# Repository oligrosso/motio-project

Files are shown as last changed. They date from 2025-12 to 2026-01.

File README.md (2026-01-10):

# 🧠 MOTIO — Biomedical Instrumentation Project

**MOTIO** is an end-to-end **biomedical instrumentation system** designed for the **analysis and treatment support of Parkinson’s Disease**, providing a **non-invasive, portable, and objective** approach to motor symptom monitoring.

The project integrates **wearable hardware**, **embedded firmware**, and an **intelligent analysis platform**, enabling both clinical and ambulatory use.

> 🩺 *Making motion science accessible.*

---

## 🎯 Project Objective

The main goal of MOTIO is to develop and validate a system capable of:

- 🧤 Delivering **vibrotactile therapeutic stimulation**
- 📟 Objectively measuring motor symptoms, especially tremor
- 📊 Processing and visualizing motion data through a clinical interface
- 📈 Complementing (not replacing) traditional clinical assessments (e.g. MDS-UPDRS)

---

## 🧩 System Architecture Overview

### 📁 Repository Structure

- 🧤 **MotioGlove/** — Wearable vibrotactile therapeutic device  
- 📟 **MotioSensor/** — Portable inertial measurement device (IMU)  
- 📊 **MotioMetrics/** — Motion analysis and visualization platform  

Each module can operate independently, but together they form a **complete ecosystem** for treatment, measurement, and analysis.

---

## 🧤 MotioGlove — Vibrotactile Therapeutic Glove

Wearable glove designed to apply **Vibrotactile Coordinated Reset (vCR)** stimulation to the fingertips.

### 🔬 Scientific Background
Based on research by **Tass et al. (Stanford University)**, vCR aims to **desynchronize pathological neural networks** using controlled mechanical stimulation.

### ⚙️ Key Features
- Vibrotactile stimulation at **250 Hz**
- Alternating stimulation of **finger pairs**
- Randomized stimulation sequences (**Fisher–Yates algorithm**)
- Temporal pauses with **jitter**
- Autonomous **2-hour therapy sessions**
- Button-based control and LED feedback

### ✅ Advantages
- Non-invasive
- Portable
- Ambulatory use
- High patient comfort
- No reported side effects

---

## 📟 MotioSensor — Inertial Measurement Device

Portable sensing unit designed to objectively capture motion data with **clinical-grade precision**.

### 🧠 Measured Signals
- 3-axis acceleration
- 3-axis angular velocity
- Orientation estimation (Yaw, Pitch, Roll)

### 🔄 Operating Modes
- 🏥 **Clinical mode**: real-time WiFi transmission
- 🏠 **Ambulatory mode**: local storage on microSD card

### 📁 Output
- `.csv` files containing:
  - Raw sensor signals
  - Timestamped activity annotations

---

## 📊 MotioMetrics — Motion Analysis Platform

Software platform responsible for **data processing, analysis, and visualization**.

### 🧠 Backend (Python)
- CSV file ingestion
- Automatic signal processing
- Tremor episode detection
- Computation of:
  - Dominant frequency
  - RMS amplitude
  - Episode duration
- Spectral analysis (FFT + **Burg method**)

### 🖥️ Web Interface
- Clinical-oriented UI
- Manual CSV upload
- Interactive visualizations (Plotly.js)
- Patient data registration
- PDF report export
- Local measurement history

### 🔴 Real-Time Analysis
- **WebSocket-based** communication
- Live signal visualization
- Activity logging with timestamps
- Automatic download of recorded data at session end

---

## 🔁 System Workflow

### 🧪 Real-Time Analysis
```mermaid
flowchart LR
  A[MotioSensor] -->|WiFi / WebSockets| B[MotioMetrics backend]
  B --> C[Live processing]
  C --> D[Web interface]
  D --> E[Live visualization]
```

### 📂 Offline CSV Analysis

```mermaid
flowchart LR
  A[MotioSensor<br/>CSV files] --> B[MotioMetrics]
  B --> C[Signal processing]
  C --> D[Metrics extraction]
  D --> E[Reports and visualizations]
```
## 🧪 Validation & Results

The system was evaluated on:
- Parkinson’s patients with tremor
- Parkinson’s patients without tremor (dyskinesia)
- Control subjects

Results demonstrated:
- Strong correlation with clinical evaluation
- Robust tremor episode detection
- High usability and acceptance by patients and clinicians

---

## 🛠️ Technologies Used

- **Python** (signal processing & backend)
- **Flask + Socket.IO**
- **JavaScript / HTML / CSS**
- **Plotly.js**
- **ESP8266 (Wemos D1 Mini)**
- **MPU6050 IMU**
- **Render + GitHub**

---

## 👩‍🔬 Team

Developed as part of  
**Biomedical Instrumentation II — ITBA**

**Group 1**
- Alexa Sessarego Aurich
- Jazmín Azul Fermani  
- Olivia Grosso  
---

## ⚠️ Disclaimer

This project was developed for **academic and research purposes only**.  
It is **not a certified medical device** for commercial clinical use.

## 🗂️ Module Interaction Diagram
```mermaid
flowchart LR

  subgraph Wearables
    G[MotioGlove<br/>Vibrotactile therapy]
    P[Patient]
    S[MotioSensor<br/>IMU data acquisition]
    G -->|Therapy| P -->|Motion| S
  end

  subgraph Software
    B[MotioMetrics backend]
    W[Web interface]
    D[Desktop application]
    B --> W
    B --> D
  end

  S -->|Motion data| B

```

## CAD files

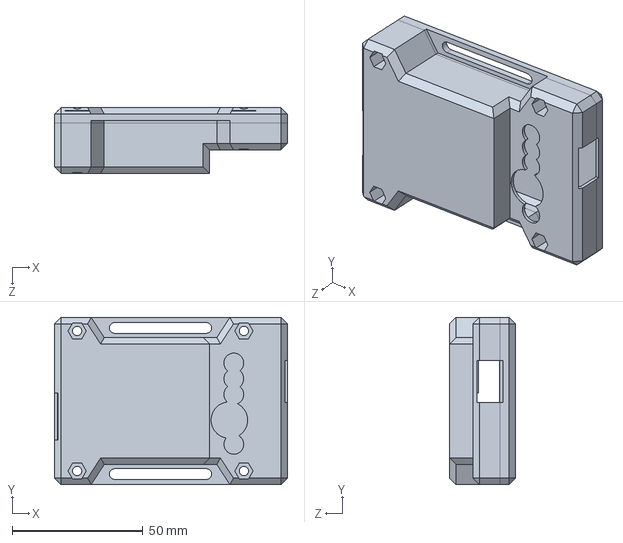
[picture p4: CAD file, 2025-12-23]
MotioGlove/3DPrint/MotioGlove_ambaspartes.SLDPRT
89.0 x 63.9 x 25.2 mm

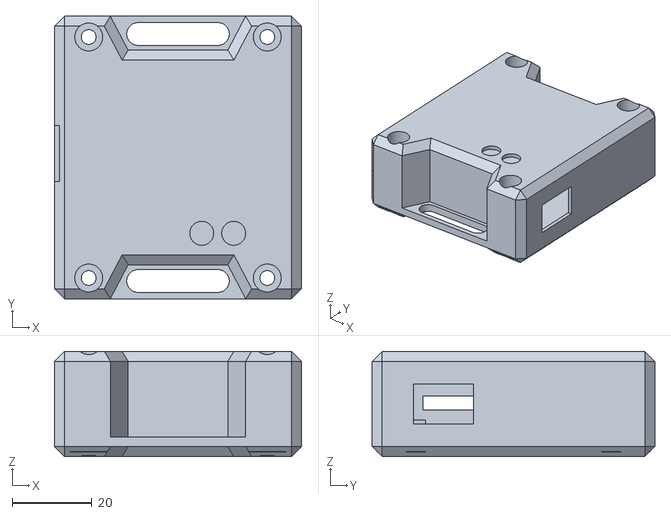
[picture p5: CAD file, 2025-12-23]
MotioSensor/3DPrint/MotioSensor_Carcasa.STL
61.9 x 70.8 x 26.4

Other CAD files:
MotioGlove/3DPrint/MotioGlove_carcasa_ambaspartes.STL
MotioSensor/3DPrint/MotioSensor_ambaspartes.SLDPRT

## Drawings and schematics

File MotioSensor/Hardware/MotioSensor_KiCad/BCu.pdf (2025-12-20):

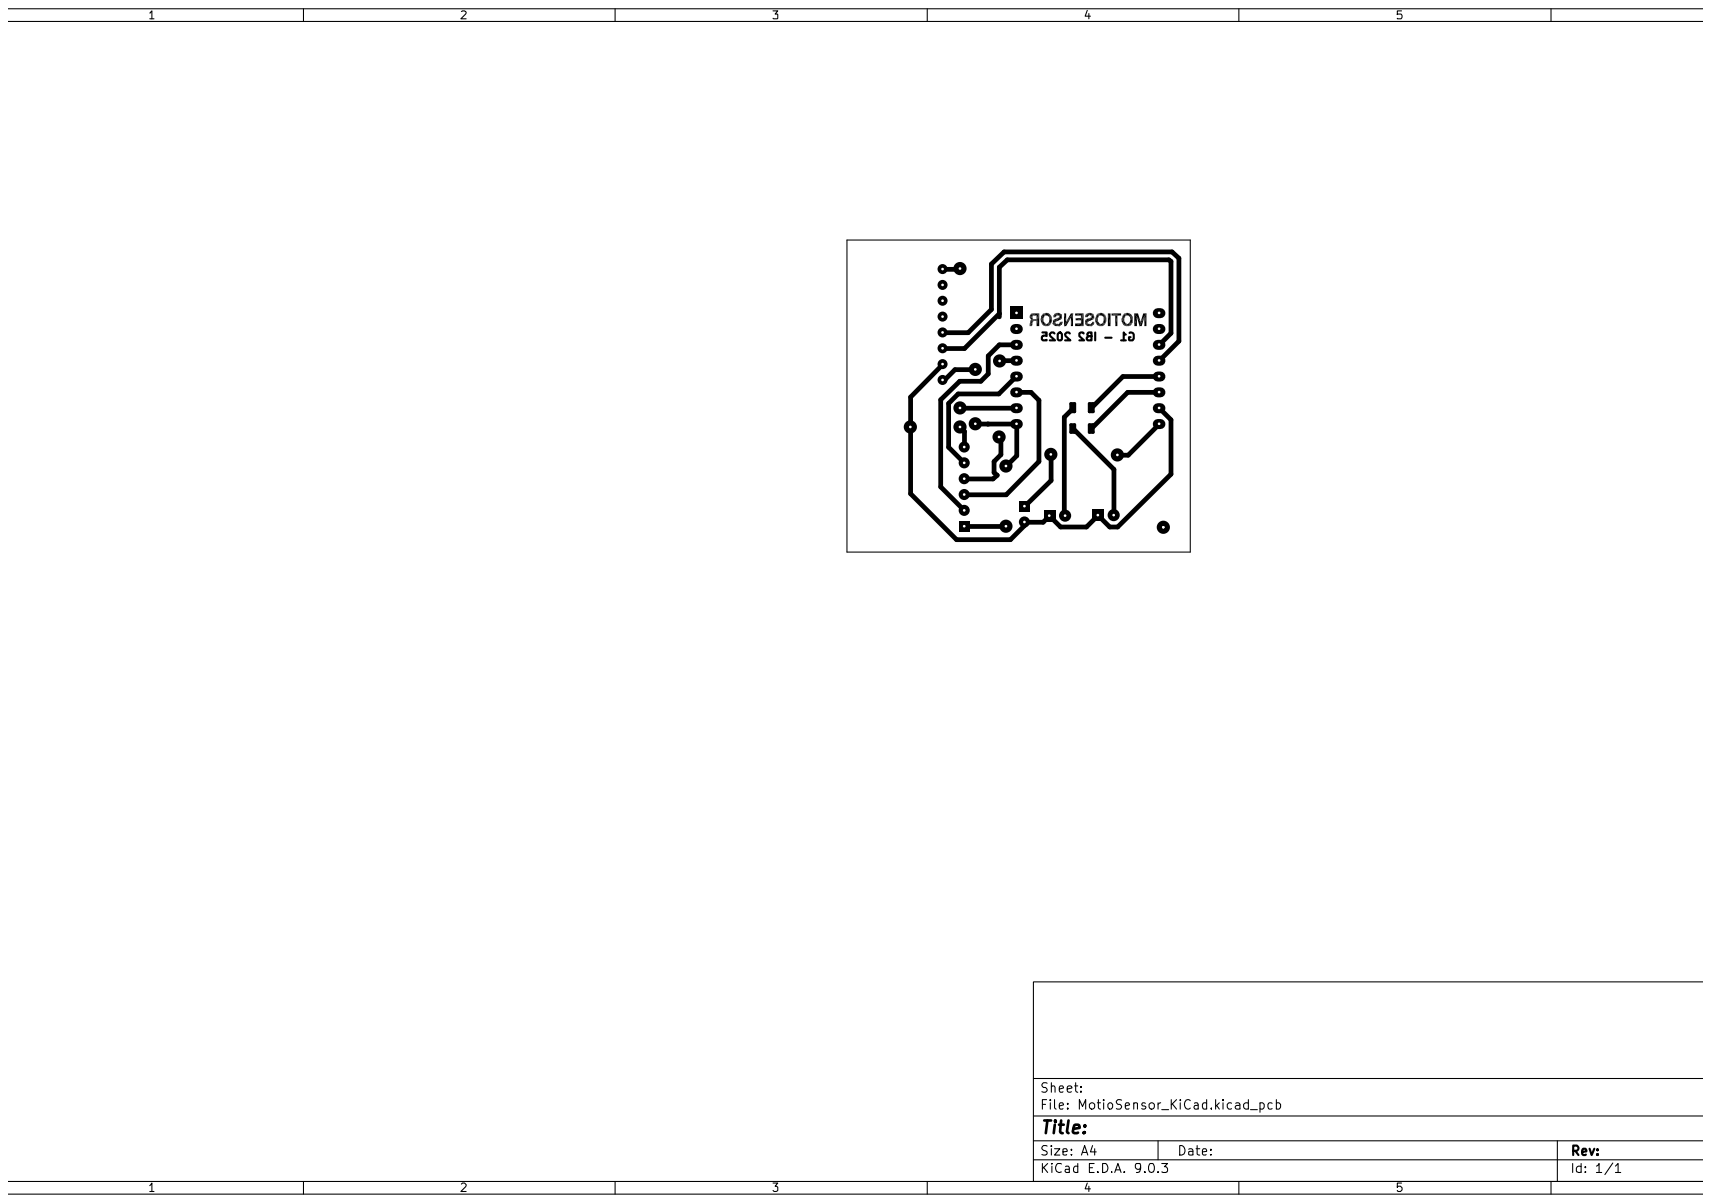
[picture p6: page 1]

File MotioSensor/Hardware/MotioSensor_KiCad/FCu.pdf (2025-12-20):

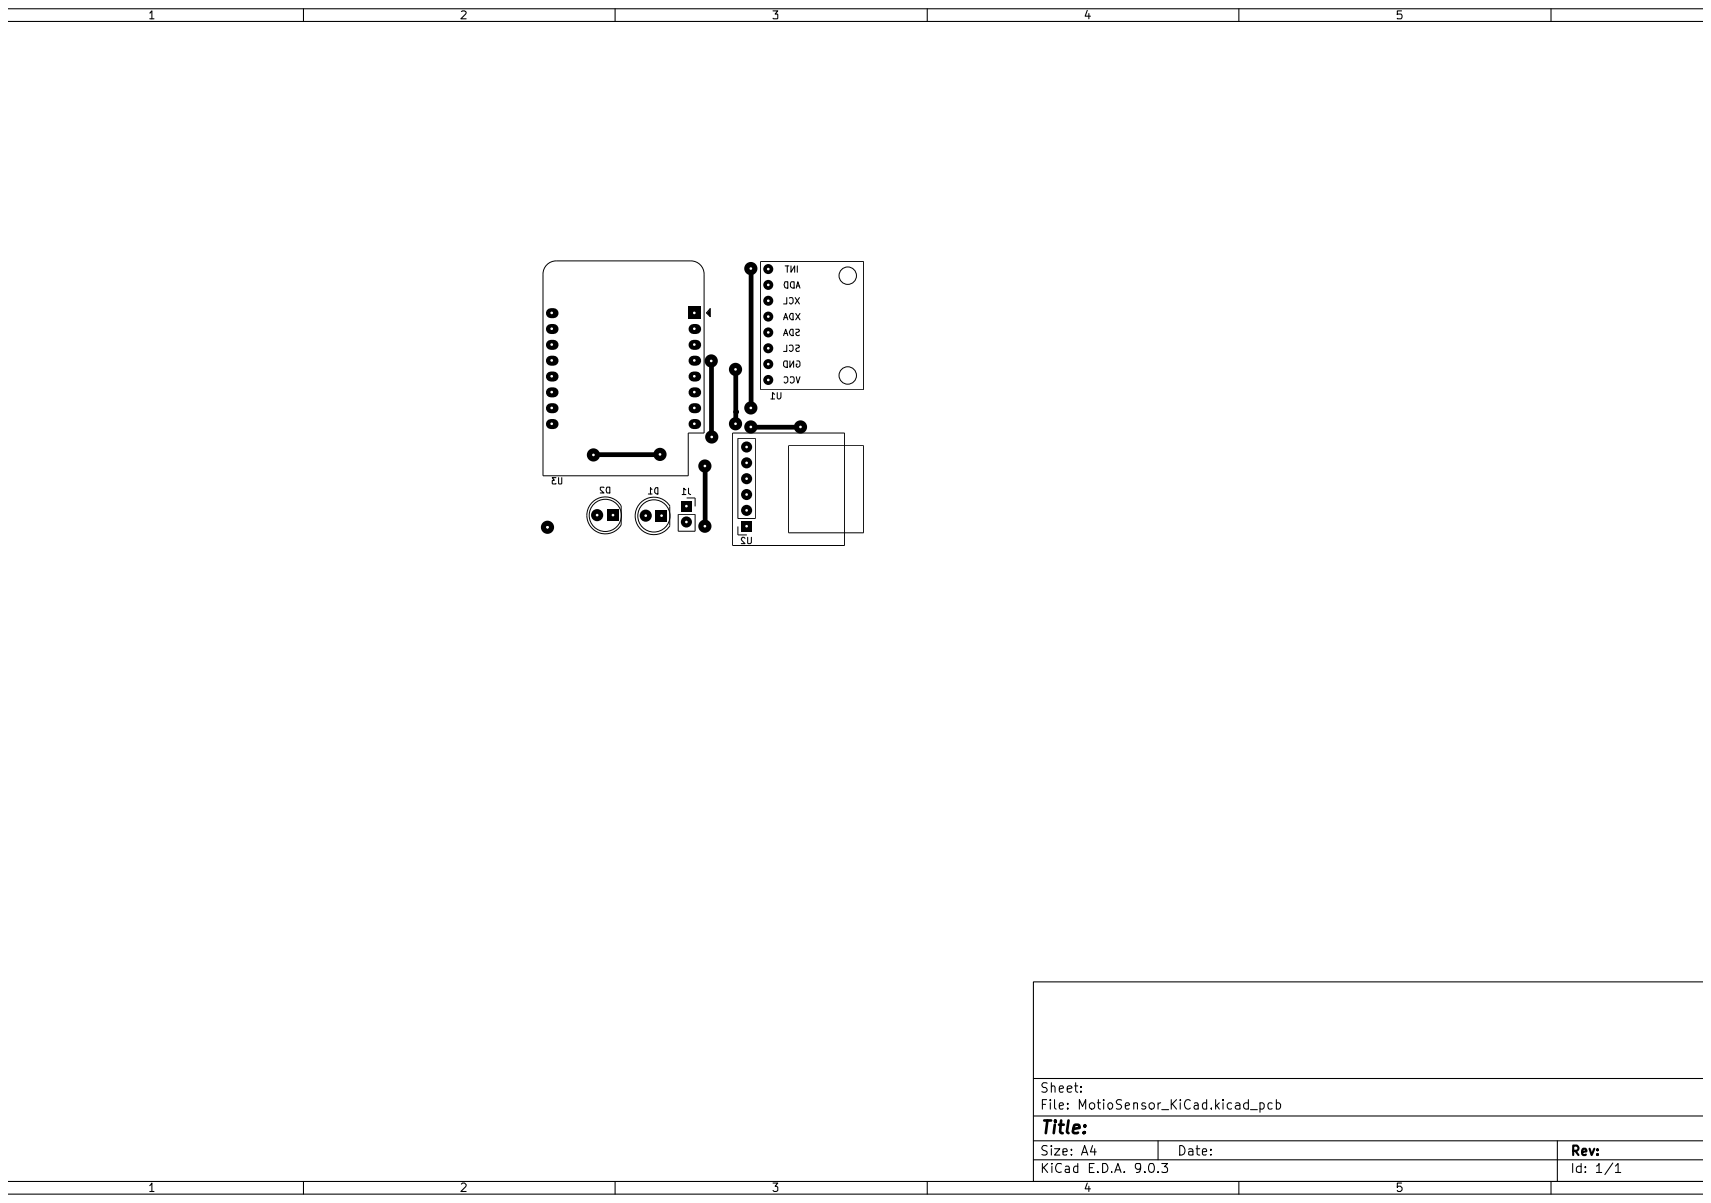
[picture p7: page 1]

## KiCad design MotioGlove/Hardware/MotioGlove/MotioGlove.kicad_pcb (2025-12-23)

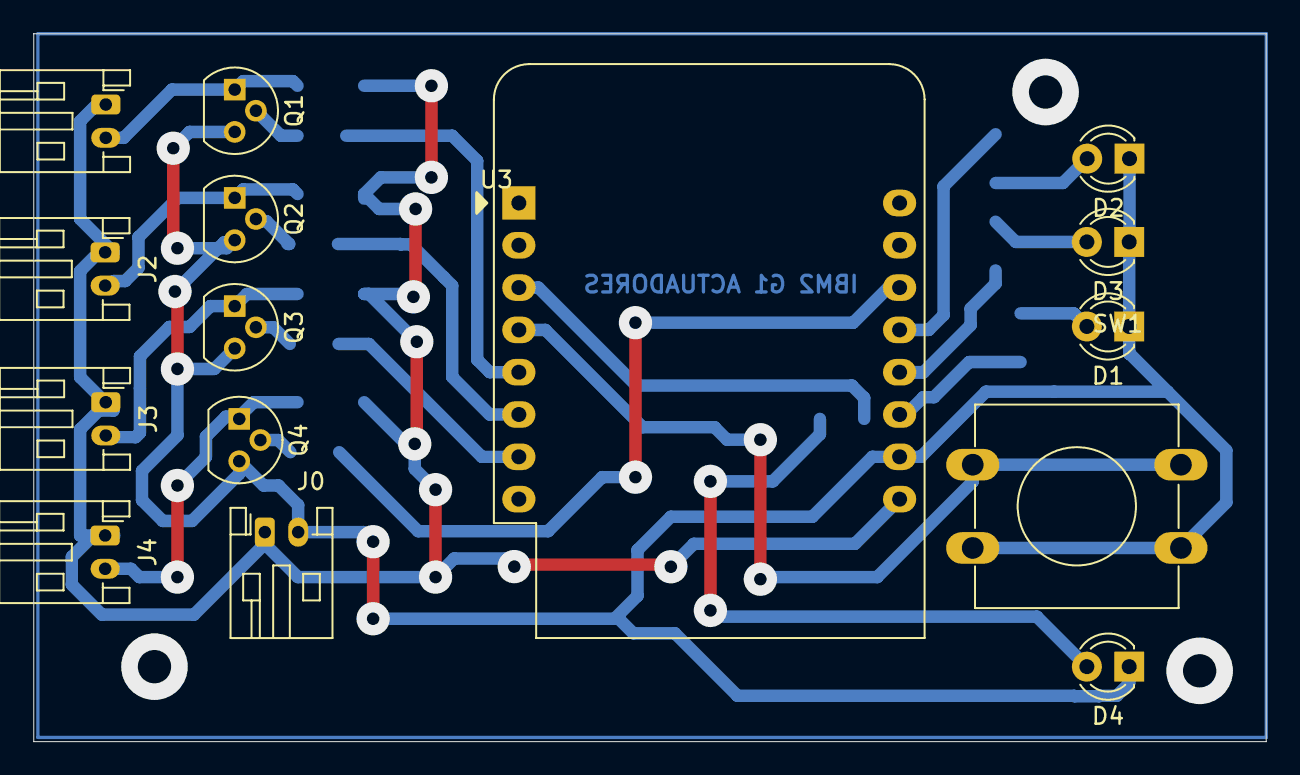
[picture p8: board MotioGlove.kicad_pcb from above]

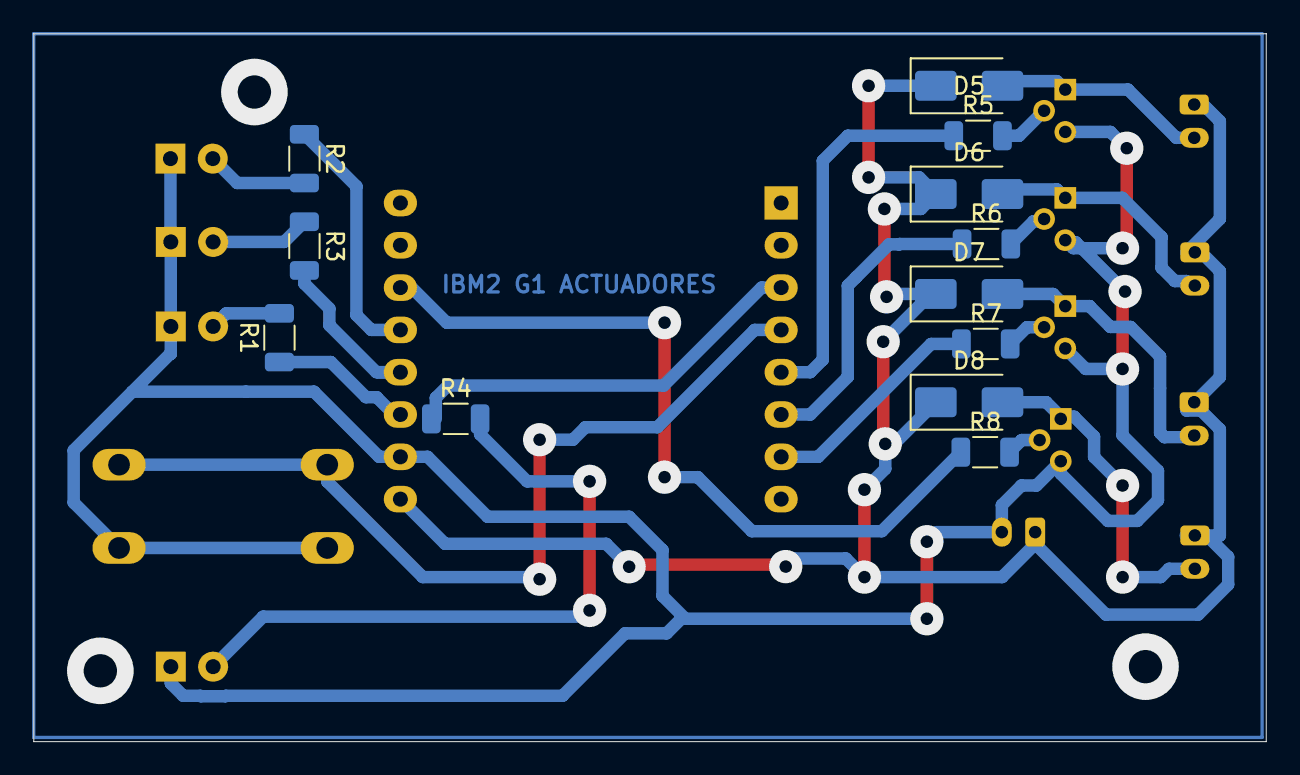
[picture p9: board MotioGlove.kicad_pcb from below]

Board: 2 copper layers, 74.0 x 42.5 mm, 27 parts (12 on the bottom side), 23 nets.

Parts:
D1, D2, D3: LED; LED_D3.0mm
D4: LED_STATUS; LED_D3.0mm
D5, D6, D7, D8: D; D_SMA
J0: 5V; JST_PH_S2B-PH-K_1x02_P2.00mm_Horizontal
J1, J2, J3, J4: Conn_01x02; JST_PH_S2B-PH-K_1x02_P2.00mm_Horizontal
Q1, Q2, Q3, Q4: BC547; TO-92
R1, R2, R3, R4, R5, R6, R7, R8: R; R_1206_3216Metric
SW1: SW_Push; SW_PUSH-12mm
U3: WEMOS_D1_mini; WEMOS_D1_mini_light

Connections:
/5V: D5.1 (K), D6.1 (K), D7.1 (K), D8.1 (K), J0.1, J1.1, J2.1, J3.1, J4.1, U3.9 (5V)
/D0: R4.1, U3.3 (D0)
/D1: R8.1, U3.14 (SCL/D1)
/D2: R2.1, U3.13 (SDA/D2)
/D3: R3.2, U3.12 (D3)
/D4: R1.1, U3.11 (D4)
/D5: SW1.1, U3.4 (SCK/D5)
/D6: R5.1, U3.5 (MISO/D6)
/D7: R6.1, U3.6 (MOSI/D7)
/D8: R7.1, U3.7 (CS/D8)
/GND: D1.1 (K), D2.1 (K), D3.1 (K), D4.1 (K), J0.2, Q1.3 (E), Q2.3 (E), Q3.3 (E), Q4.3 (E), SW1.2, U3.10 (GND)
unnamed: D1.2 (A), R1.2
unnamed: D2.2 (A), R2.2
unnamed: D3.2 (A), R3.1
unnamed: D4.2 (A), R4.2
unnamed: D5.2 (A), J1.2, Q1.1 (C)
unnamed: D6.2 (A), J2.2, Q2.1 (C)
unnamed: D7.2 (A), J3.2, Q3.1 (C)
unnamed: D8.2 (A), J4.2, Q4.1 (C)
unnamed: Q1.2 (B), R5.2
unnamed: Q2.2 (B), R6.2
unnamed: Q3.2 (B), R7.2
unnamed: Q4.2 (B), R8.2

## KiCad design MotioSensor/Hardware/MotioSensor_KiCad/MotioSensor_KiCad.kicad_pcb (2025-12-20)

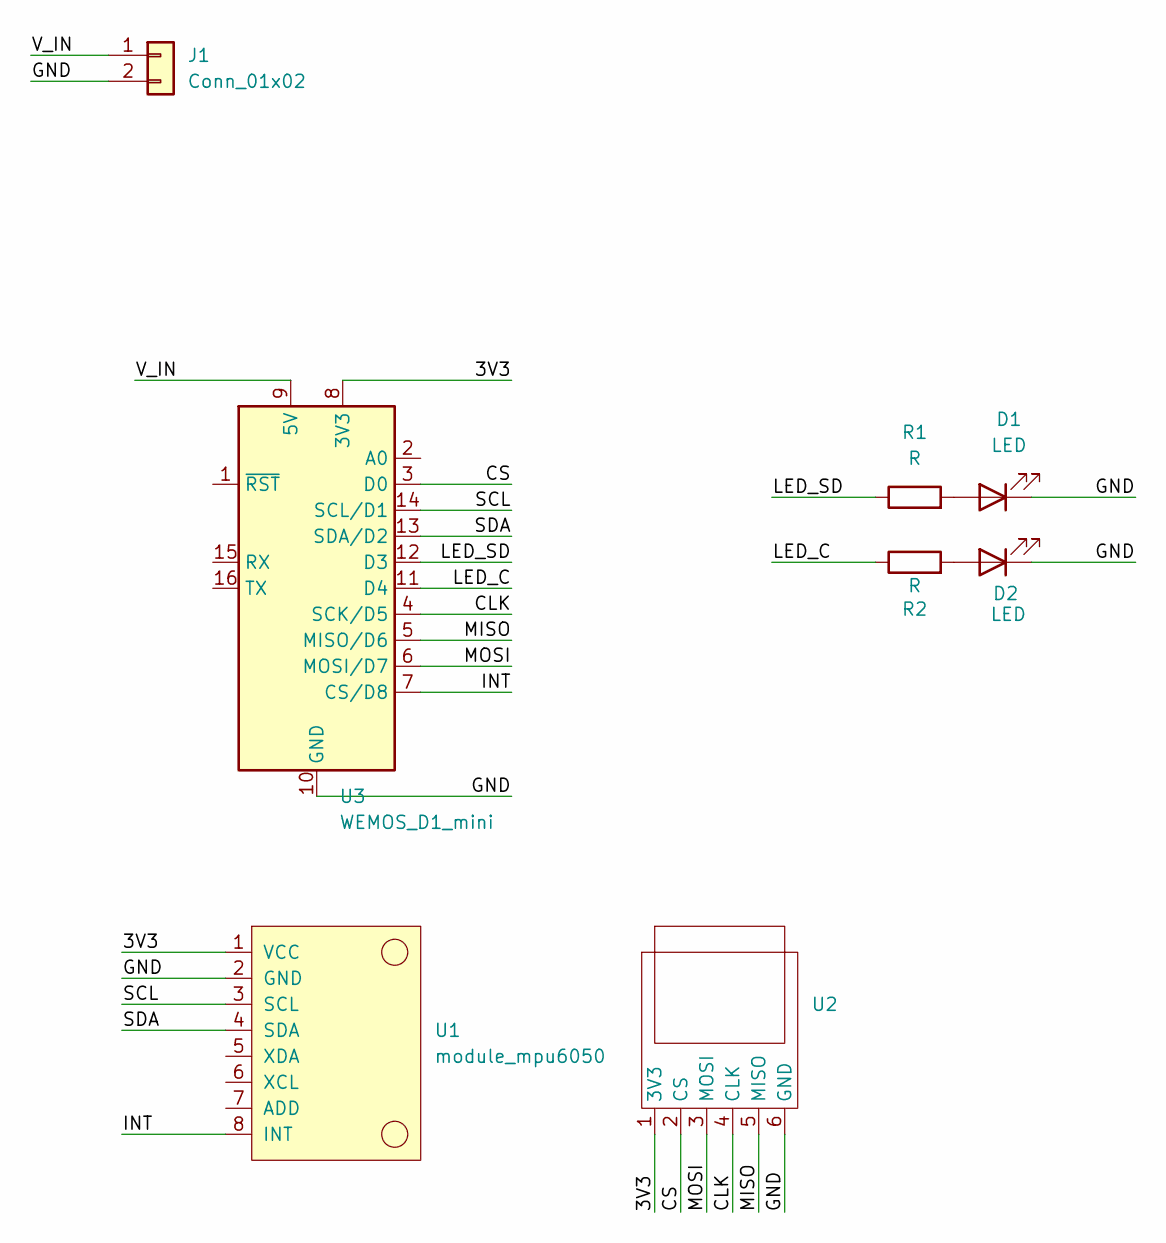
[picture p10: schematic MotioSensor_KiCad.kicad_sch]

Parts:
D1, D2: LED; LED_D5.0mm
J1: Conn_01x02; PinHeader_1x02_P2.54mm_Vertical
R1, R2: R; R_1206_3216Metric
U1: module_mpu6050
U2: PinHeader_1x06_P2.54mm_Vertical
U3: WEMOS_D1_mini; WEMOS_D1_mini_light

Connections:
/3V3: U1.1 (VCC), U2.1 (3V3), U3.8 (3V3)
/CLK: U2.4 (CLK), U3.4 (SCK/D5)
/CS: U2.2 (CS), U3.3 (D0)
/GND: D1.1 (K), D2.1 (K), J1.2, U1.2 (GND), U2.6 (GND), U3.10 (GND)
/INT: U1.8 (INT), U3.7 (CS/D8)
/LED_C: R2.1, U3.11 (D4)
/LED_SD: R1.1, U3.12 (D3)
/MISO: U2.5 (MISO), U3.5 (MISO/D6)
/MOSI: U2.3 (MOSI), U3.6 (MOSI/D7)
/SCL: U1.3 (SCL), U3.14 (SCL/D1)
/SDA: U1.4 (SDA), U3.13 (SDA/D2)
/V_IN: J1.1, U3.9 (5V)
unnamed: D1.2 (A), R1.2
unnamed: D2.2 (A), R2.2

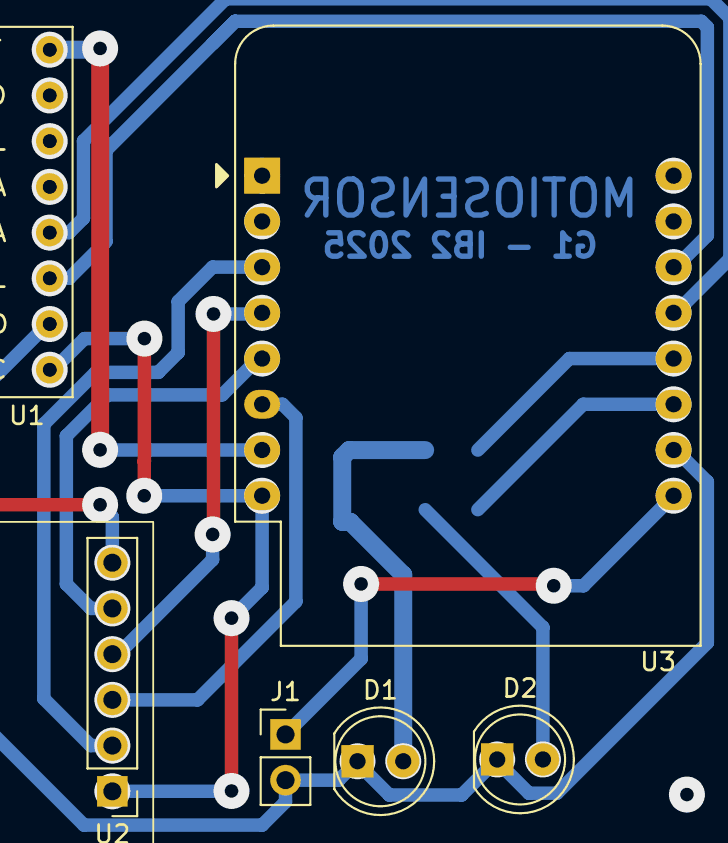
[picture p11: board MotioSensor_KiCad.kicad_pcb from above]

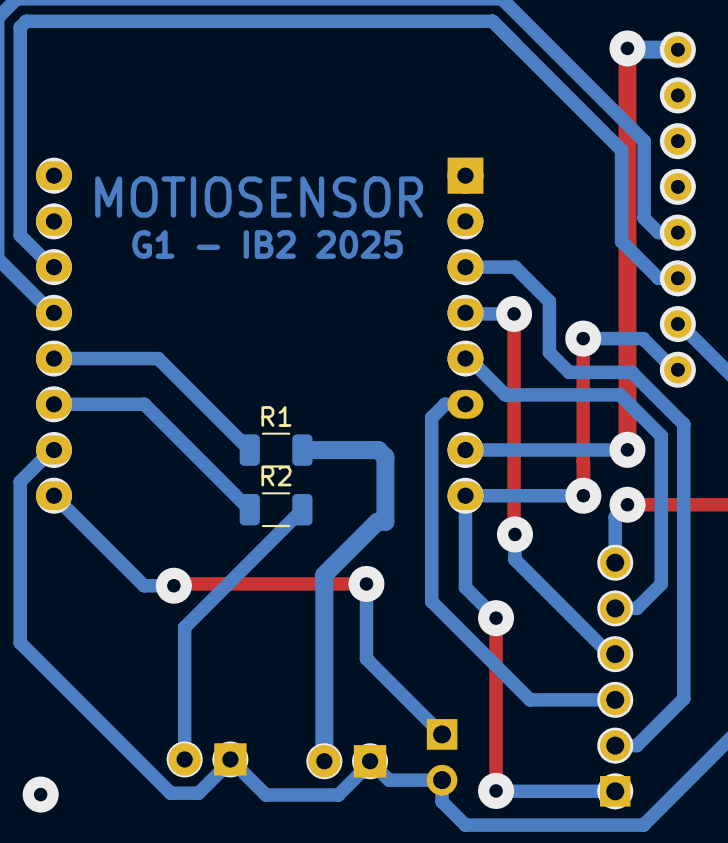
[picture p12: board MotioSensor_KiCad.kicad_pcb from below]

Board: 2 copper layers, 8 parts (2 on the bottom side), 14 nets.

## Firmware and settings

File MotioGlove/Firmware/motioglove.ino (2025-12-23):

/*
 * ========================================================================
 * GUANTE TERAPÉUTICO PARA ENFERMEDAD DE PARKINSON
 * Estimulación de Reset Coordinada Vibrotáctil (vCR)
 * ========================================================================
 * 
 * Basado en investigación de Stanford Medicine (Dr. Peter Tass)
 * Publicación: Frontiers in Physiology, Abril 2021
 * 
 * DESCRIPCIÓN:
 * Este dispositivo aplica vibraciones coordinadas a las yemas de los dedos
 * para desincronizar la actividad neuronal anormal característica del
 * Parkinson's, aliviando síntomas motores y no motores.
 * 
 * PROTOCOLO DE TRATAMIENTO:
 * - Duración: 2 horas por sesión
 * - Frecuencia: 2 sesiones diarias (mañana y tarde/noche)
 * - Frecuencia de vibración: 250 Hz
 * - Dedos estimulados: Índice, medio, anular y meñique
 * 
 * AUTOR: [Tu Nombre]
 * FECHA: Octubre 2024
 * VERSIÓN: 2.0 - Código Completo con Todas las Mejoras
 * ========================================================================
 */

#include <Arduino.h>

// ========================================================================
// CONFIGURACIÓN DE HARDWARE
// ========================================================================

// Pines para los 4 motores de vibración (uno por dedo: índice, medio, anular, meñique)
// NOTA: Se evitan GPIO0 (D3) y GPIO15 (D8) por conflictos en ESP8266 boot
#define MOTOR1 D1  // GPIO5  - Motor dedo índice
#define MOTOR2 D0  // GPIO14 - Motor dedo medio
#define MOTOR3 D7  // GPIO12 - Motor dedo anular
#define MOTOR4 D6  // GPIO13 - Motor dedo meñique

//  --- BOTÓN DE CONTROL --- (usa pin seguro)
#define BUTTON D5  // GPIO16 - Botón multifunción (Inicio/Pausa/Stop) (a gnd cuando se presiona)

// LEDs indicadores de progreso del tratamiento (2 horas dividida en 3 segmentos de 40 min)
#define LED1 D2    // GPIO4  - LED 1:  LED 1: Se enciende a los 40 min
#define LED2 D3    // GPIO0  - LED 2: Se enciende a los 80 min  ⚠️ puede interferir (ver abajo)
#define LED3 D4    // GPIO2  - LED 3: Se enciende a los 120 min (FIN) (LED_BUILTIN)

// --- LED DE ESTADO OPERATIVO ---
#define LED_STATUS D8  // GPIO15 - Parpadea mientras el tratamiento está activo

// ========================================================================
// CONSTANTES DEL PROTOCOLO vCR (Valores respaldados por investigación)
// ========================================================================

// Frecuencia de vibración objetivo: 250 Hz
// Período = 1/250Hz = 4000 microsegundos
// Ciclo de trabajo 50%: 2000µs ON + 2000µs OFF
#define VIBRATION_FREQUENCY_HZ 250
#define PULSE_ON_TIME_US 2000      // Tiempo que el motor está encendido
#define PULSE_OFF_TIME_US 2000     // Tiempo que el motor está apagado
#define PULSES_PER_BURST 97        // Número de pulsos por ráfaga de vibración

// Jitter entre estímulos (variación aleatoria ±23.5% del promedio)
// Promedio: 66.666 ms → Rango: 51 ms a 82.332 ms
#define JITTER_MIN_US 51000        // Jitter mínimo: 51 milisegundos
#define JITTER_MAX_US 82332        // Jitter máximo: 82.332 milisegundos

// Pausa larga después de 3 secuencias completas vCR
// Esta pausa es CRÍTICA para el efecto terapéutico
#define LONG_PAUSE_US 799992       // ~800 milisegundos
#define LONG_PAUSE_MS 1500         // 1.5 segundos adicionales

// Duración total del tratamiento: 2 HORAS (protocolo Stanford)
#define TREATMENT_DURATION_HOURS 2
#define TREATMENT_DURATION_MS (TREATMENT_DURATION_HOURS * 60UL * 60UL * 1000UL)

// Tiempos para encendido progresivo de LEDs (cada 40 minutos)
#define LED1_TIME_MS (40UL * 60UL * 1000UL)   // 40 minutos
#define LED2_TIME_MS (80UL * 60UL * 1000UL)   // 80 minutos
#define LED3_TIME_MS (120UL * 60UL * 1000UL)  // 120 minutos (2 horas)

// Debounce del botón (evita lecturas múltiples por rebote mecánico)
#define DEBOUNCE_DELAY_MS 50

// Parpadeo del LED de estado (indica operación activa)
#define STATUS_LED_BLINK_MS 1000   // Parpadea cada 1 segundo

// ========================================================================
// VARIABLES GLOBALES
// ========================================================================

// --- CONTROL DE ESTADO DEL SISTEMA ---
enum SystemState {
  IDLE,           // Sistema en reposo, esperando inicio
  RUNNING,        // Tratamiento en ejecución
  PAUSED,         // Tratamiento pausado por el usuario
  COMPLETED,      // Tratamiento completado (2 horas)
 // TEST_MODE       // Modo de prueba (mantener botón 5 seg al inicio)
};

SystemState currentState = IDLE;

// --- VARIABLES DE TIEMPO ---
unsigned long treatmentStartTime = 0;     // Momento de inicio del tratamiento
unsigned long pauseStartTime = 0;         // Momento de inicio de pausa
unsigned long totalPausedTime = 0;        // Tiempo total acumulado en pausa
unsigned long lastButtonCheck = 0;        // Última verificación del botón (debounce)
unsigned long lastStatusBlink = 0;        // Última vez que parpadeó LED de estado
bool statusLedState = false;              // Estado actual del LED de estado

// --- VARIABLES DE SECUENCIA vCR ---
int fingerSequence[] = { 0, 1, 2, 3 };    // Orden aleatorio de dedos (0=MOTOR1, 3=MOTOR4)
int sequenceIndex = 0;                    // Índice actual en la secuencia (0-3)
int vcrCycleCount = 0;                    // Contador de ciclos vCR (0-2)
int activeMotor1 = 0;                     // Primer motor activo en este ciclo
int activeMotor2 = 0;                     // Segundo motor activo en este ciclo

// --- VARIABLES DE JITTER ---
unsigned long interStimulusJitter = 0;    // Jitter individual para próxima pausa
unsigned long cumulativeJitter = 0;       // Acumulación de jitter para compensación

// --- CONTADOR DE SESIONES (para futuro uso con EEPROM) ---
// int dailySessions = 0;  // Descomenta si implementas memoria persistente

// ========================================================================
// DECLARACIÓN DE FUNCIONES
// ========================================================================

void initializeSystem();
void waitForButtonPress();
void handleButtonPress();
bool isButtonPressed();
void startTreatment();
void pauseTreatment();
void resumeTreatment();
void completeTreatment();
void runTreatmentCycle();
void generateVibroBurst(int motor1, int motor2);
void selectNextFingerPair();
void shuffleFingerSequence();
void updateProgressLEDs();
void updateStatusLED();
void blinkAllLEDs(int times, int delayMs);
//void testMode();
unsigned long getElapsedTreatmentTime();
void printStatusToSerial();
String getStateName(SystemState state);

// ========================================================================
// SETUP: Inicialización del sistema
// ========================================================================

void setup() {
  // Inicializar comunicación serial para debug (opcional)
  Serial.begin(115200);
  Serial.println("\n========================================");
  Serial.println("GUANTE TERAPÉUTICO PARKINSON vCR 2.0");
  Serial.println("========================================\n");
  
  initializeSystem();
  
  // Indicar que el sistema está listo
  blinkAllLEDs(3, 200);  // Parpadear 3 veces = Sistema listo
  Serial.println("Sistema listo. Presione el botón para iniciar.");
  Serial.println("Mantenga presionado 5 seg para modo PRUEBA.\n");
}

// ========================================================================
// LOOP PRINCIPAL: Máquina de estados
// ========================================================================

void loop() {
  // Manejar eventos del botón (con debounce)
  if (millis() - lastButtonCheck > DEBOUNCE_DELAY_MS) {
    handleButtonPress();
    lastButtonCheck = millis();
  }
  
  // Ejecutar acciones según el estado actual
  switch (currentState) {
    case IDLE:
      // Esperando que el usuario presione el botón
      updateStatusLED();  // Parpadeo lento = esperando
      break;
      
    case RUNNING:
      // Ejecutar un ciclo completo de tratamiento
      runTreatmentCycle();// <--- Esta es la prioridad (baja latencia)
      updateProgressLEDs();
      updateStatusLED();
      printStatusToSerial(); // <--- me imprime el tiempo restante de tratamiento
      
      // Verificar si se completó el tratamiento (2 horas)
      if (getElapsedTreatmentTime() >= TREATMENT_DURATION_MS) {
        completeTreatment();
      }
      break;
      
    case PAUSED:
      // Tratamiento pausado - solo parpadear LED de estado
      updateStatusLED();
      break;
      
    case COMPLETED:
      // Tratamiento completado - esperar reinicio
      // Los LEDs ya están todos encendidos
      break;
    /*  
    case TEST_MODE:
      // Modo de prueba ya se ejecutó en setup, volver a IDLE
      currentState = IDLE;
      break;
    */
  }
}

// ========================================================================
// FUNCIONES DE INICIALIZACIÓN
// ========================================================================

/**
 * Configura todos los pines y variables del sistema
 */
void initializeSystem() {
  // Configurar pines de motores como salida (inicialmente apagados)
  pinMode(MOTOR1, OUTPUT);
  pinMode(MOTOR2, OUTPUT);
  pinMode(MOTOR3, OUTPUT);
  pinMode(MOTOR4, OUTPUT);
  digitalWrite(MOTOR1, LOW);
  digitalWrite(MOTOR2, LOW);
  digitalWrite(MOTOR3, LOW);
  digitalWrite(MOTOR4, LOW);
  
  // Configurar LEDs de progreso como salida (inicialmente prendidos)
  pinMode(LED1, OUTPUT);
  pinMode(LED2, OUTPUT);
  pinMode(LED3, OUTPUT);
// Iniciar LEDs de progreso en ALTO (HIGH)
  digitalWrite(LED1, HIGH);
  digitalWrite(LED2, HIGH);
  digitalWrite(LED3, HIGH);
  
  // Configurar LED de estado como salida
  pinMode(LED_STATUS, OUTPUT);
  digitalWrite(LED_STATUS, LOW);
  
  // Configurar botón con resistencia pull-up interna
  // El botón conecta el pin a GND cuando se presiona
  pinMode(BUTTON, INPUT_PULLUP);
  
  // Inicializar generador de números aleatorios
  // Usa ruido analógico como semilla para mejor aleatoriedad
  randomSeed(analogRead(A0));
  
  // Generar primera secuencia aleatoria de dedos
  shuffleFingerSequence();
  
  // Verificar si se mantiene presionado el botón al iniciar (MODO PRUEBA)
  //if (isButtonPressed()) {
  //  unsigned long pressStart = millis();
  //  while (isButtonPressed() && (millis() - pressStart < 5000)) {
  //    delay(10);
  //  }
  //  if (millis() - pressStart >= 5000) {
  //    testMode();
  //  }
  //}
}

// ========================================================================
// FUNCIONES DE CONTROL DE ESTADO
// ========================================================================

/**
 * Verifica si el botón está presionado (con lógica invertida por pull-up)
 */
bool isButtonPressed() {
  return digitalRead(BUTTON) == LOW;
}

/**
 * Maneja las pulsaciones del botón según el estado actual
 * - IDLE: Inicia el tratamiento
 * - RUNNING: Pausa el tratamiento
 * - PAUSED: Resume el tratamiento
 * - COMPLETED: Reinicia el sistema
 */
 
void handleButtonPress() {
  static bool lastButtonState = HIGH;
  bool currentButtonState = digitalRead(BUTTON);
  
  // Detectar transición de HIGH a LOW (botón recién presionado)
  if (lastButtonState == HIGH && currentButtonState == LOW) {
    switch (currentState) {
      case IDLE:
        startTreatment();
        break;
      case RUNNING:
        pauseTreatment();
        break;
      case PAUSED:
        resumeTreatment();
        break;
      case COMPLETED:
        // Reiniciar el sistema
        Serial.println("\n=== REINICIANDO SISTEMA ===");
        currentState = IDLE;
        treatmentStartTime = 0;
        totalPausedTime = 0;
        sequenceIndex = 0;
        vcrCycleCount = 0;
        digitalWrite(LED1, LOW);
        digitalWrite(LED2, LOW);
        digitalWrite(LED3, LOW);
        blinkAllLEDs(2, 300);
        Serial.println("Sistema reiniciado. Listo para nueva sesión.\n");
        break;
    }
  }
  
  lastButtonState = currentButtonState;
}

/**
 * Inicia el tratamiento
 */
void startTreatment() {
  Serial.println("\n=== INICIANDO TRATAMIENTO ===");
  Serial.println("Duración: 2 horas");
  Serial.println("Presione el botón para PAUSAR en cualquier momento.\n");
  
  treatmentStartTime = millis();
  totalPausedTime = 0;
  currentState = RUNNING;
  
  // Feedback visual: parpadear LED de estado rápidamente
  for (int i = 0; i < 5; i++) {
    digitalWrite(LED_STATUS, HIGH);
    delay(100);
    digitalWrite(LED_STATUS, LOW);
    delay(100);
  }
}

/**
 * Pausa el tratamiento
 */
void pauseTreatment() {
  Serial.println("\n=== TRATAMIENTO PAUSADO ===");
  Serial.println("Presione el botón para CONTINUAR.\n");
  
  pauseStartTime = millis();
  currentState = PAUSED;
  
  // Apagar todos los motores
  digitalWrite(MOTOR1, LOW);
  digitalWrite(MOTOR2, LOW);
  digitalWrite(MOTOR3, LOW);
  digitalWrite(MOTOR4, LOW);
  
  // Feedback visual: parpadear todos los LEDs
  blinkAllLEDs(2, 200);
}

/**
 * Resume el tratamiento después de una pausa
 */
void resumeTreatment() {
  Serial.println("\n=== REANUDANDO TRATAMIENTO ===\n");
  
  // Acumular el tiempo que estuvo en pausa
  totalPausedTime += (millis() - pauseStartTime);
  currentState = RUNNING;
  
  // Feedback visual
  blinkAllLEDs(2, 200);
}

/**
 * Completa el tratamiento (2 horas alcanzadas)
 */
void completeTreatment() {
  Serial.println("\n========================================");
  Serial.println("¡TRATAMIENTO COMPLETADO!");
  Serial.println("Duración: 2 horas");
  Serial.println("========================================");
  Serial.println("\nPresione el botón para iniciar nueva sesión.\n");
  
  currentState = COMPLETED;
  
  // Apagar todos los motores
  digitalWrite(MOTOR1, LOW);
  digitalWrite(MOTOR2, LOW);
  digitalWrite(MOTOR3, LOW);
  digitalWrite(MOTOR4, LOW);
  
  // Encender todos los LEDs de progreso
  digitalWrite(LED1, HIGH);
  digitalWrite(LED2, HIGH);
  digitalWrite(LED3, HIGH);
  
  // Secuencia de celebración: parpadear LEDs rápidamente
  for (int i = 0; i < 10; i++) {
    digitalWrite(LED_STATUS, HIGH);
    delay(100);
    digitalWrite(LED_STATUS, LOW);
    delay(100);
  }
  
  // Dejar LED de estado encendido permanentemente
  digitalWrite(LED_STATUS, LOW);
}

// ========================================================================
// FUNCIONES DE TRATAMIENTO vCR
// ========================================================================

/**
 * Ejecuta un ciclo completo de tratamiento vCR:
 * 1. Genera ráfaga de vibración (97 pulsos a 250 Hz)
 * 2. Aplica pausa con jitter aleatorio
 * 3. Avanza al siguiente par de dedos
 * 4. Después de 3 secuencias completas: pausa larga
 */
void runTreatmentCycle() {
  // FASE 1: Generar ráfaga de vibración en el par de dedos actual
  generateVibroBurst(activeMotor1, activeMotor2);
  
  // FASE 2: Avanzar en la secuencia
  sequenceIndex++;
  
  if (sequenceIndex >= 4) {
    // Completamos una secuencia de 4 dedos
    sequenceIndex = 0;
    shuffleFingerSequence();  // Generar nuevo orden aleatorio
    vcrCycleCount++;
    
    if (vcrCycleCount >= 3) {
      // Completamos 3 secuencias vCR (3 x 4 dedos = 12 activaciones)
      vcrCycleCount = 0;
      
      // PAUSA LARGA: Crucial para efecto terapéutico duradero
      // Permite que el cerebro "desaprenda" patrones sincrónicos
      if (cumulativeJitter <= LONG_PAUSE_US) {
        delayMicroseconds(LONG_PAUSE_US - cumulativeJitter);
        delay(LONG_PAUSE_MS);
      } else {
        // Compensar si el jitter acumulado excedió el nominal
        delayMicroseconds((LONG_PAUSE_MS * 1000UL) - (LONG_PAUSE_US - cumulativeJitter));
      }
      cumulativeJitter = 0;  // Resetear acumulación de jitter
    }
  }
  
  // FASE 3: Seleccionar próximo par de dedos
  selectNextFingerPair();
  
  // FASE 4: Aplicar jitter inter-estímulo (variación aleatoria ±23.5%)
  // Este jitter es FUNDAMENTAL para prevenir nueva sincronización neuronal
  interStimulusJitter = random(JITTER_MIN_US, JITTER_MAX_US);
  cumulativeJitter += interStimulusJitter;
  delayMicroseconds(interStimulusJitter);
}

/**
 * Genera una ráfaga de vibración a 250 Hz en dos motores simultáneamente
 * 
 * @param motor1 Pin del primer motor
 * @param motor2 Pin del segundo motor
 */
void generateVibroBurst(int motor1, int motor2) {
  for (int pulse = 0; pulse < PULSES_PER_BURST; pulse++) {
    // Encender ambos motores
    digitalWrite(motor1, HIGH);
    digitalWrite(motor2, HIGH);
    delayMicroseconds(PULSE_ON_TIME_US);
    
    // Apagar ambos motores
    digitalWrite(motor1, LOW);
    digitalWrite(motor2, LOW);
    delayMicroseconds(PULSE_OFF_TIME_US);
  }
}

/**
 * Selecciona el próximo par de dedos a estimular
 * Estrategia: activar dedos en pares opuestos para balance
 * - Par 0: MOTOR1 (índice) + MOTOR4 (meñique)
 * - Par 1: MOTOR2 (medio) + MOTOR3 (anular)
 * - Par 2: MOTOR3 (anular) + MOTOR2 (medio)
 * - Par 3: MOTOR4 (meñique) + MOTOR1 (índice)
 */
void selectNextFingerPair() {
  int fingerPair = fingerSequence[sequenceIndex];
  
  switch (fingerPair) {
    case 0:
      activeMotor1 = MOTOR1;  // Índice
      activeMotor2 = MOTOR4;  // Meñique
      break;
    case 1:
      activeMotor1 = MOTOR2;  // Medio
      activeMotor2 = MOTOR3;  // Anular
      break;
    case 2:
      activeMotor1 = MOTOR3;  // Anular
      activeMotor2 = MOTOR2;  // Medio
      break;
    case 3:
      activeMotor1 = MOTOR4;  // Meñique
      activeMotor2 = MOTOR1;  // Índice
      break;
  }
}

/**
 * Genera un nuevo orden aleatorio de la secuencia de dedos
 * Usa el algoritmo de Fisher-Yates para mezcla uniforme
 * Pasos del algoritmo
    * Inicialización: Comienza con una secuencia de elementos (por ejemplo, un array) que se desea mezclar. 
    * Iteración hacia atrás: Recorre la secuencia desde el último elemento hasta el primero. 
    * Generar índice aleatorio: En cada iteración con índice i, genera un número entero aleatorio j entre 0 y i (inclusive). 
    * Intercambio: Intercambia el elemento en la posición actual (i) con el elemento en la posición aleatoria j. 
    * Repetir: Continúa el proceso para el siguiente elemento (decrementando i) hasta llegar al primer elemento de la lista. 
    * Resultado: Cuando el bucle finaliza, la secuencia original estará completamente mezclada. 
 */
void shuffleFingerSequence() {
  for (int i = 0; i < 4; i++) {
    int randomIndex = random(0, 4);
    // Intercambiar valores
    int temp = fingerSequence[randomIndex];
    fingerSequence[randomIndex] = fingerSequence[i];
    fingerSequence[i] = temp;
  }
}

// ========================================================================
// FUNCIONES DE FEEDBACK VISUAL
// ========================================================================

/**
 * Actualiza los LEDs de progreso según el tiempo transcurrido
 * LED1: Se enciende a los 40 minutos
 * LED2: Se enciende a los 80 minutos
 * LED3: Se enciende a los 120 minutos (2 horas - fin)
 */
void updateProgressLEDs() {
  unsigned long elapsed = getElapsedTreatmentTime();
  
  // LED3 (Apagado a 40 minutos)
  digitalWrite(LED3, (elapsed < LED1_TIME_MS) ? HIGH : LOW);

  // LED2 (Apagado a 80 minutos)
  digitalWrite(LED2, (elapsed < LED2_TIME_MS) ? HIGH : LOW);

  // LED1 (Apagado a 120 minutos)
  digitalWrite(LED1, (elapsed < LED3_TIME_MS) ? HIGH : LOW);
}

/**
 * Parpadea el LED de estado para indicar operación activa
 * Parpadeo lento (1 Hz) durante RUNNING
 * Parpadeo rápido (4 Hz) durante PAUSED
 * Encendido constante durante IDLE
 */
void updateStatusLED() {
  unsigned long currentMillis = millis();
  unsigned long blinkInterval = STATUS_LED_BLINK_MS;
  
  if (currentState == PAUSED) {
    blinkInterval = 250;  // Parpadeo rápido en pausa
  }
  
  if (currentState == RUNNING || currentState == PAUSED) {
    if (currentMillis - lastStatusBlink >= blinkInterval) {
      statusLedState = !statusLedState;
      digitalWrite(LED_STATUS, statusLedState);
      lastStatusBlink = currentMillis;
    }
  } else if (currentState == IDLE) {
    // Parpadeo muy lento en espera
    if (currentMillis - lastStatusBlink >= 2000) {
      statusLedState = !statusLedState;
      digitalWrite(LED_STATUS, statusLedState);
      lastStatusBlink = currentMillis;
    }
  }
}

/**
 * Hace parpadear todos los LEDs de progreso
 * Útil para feedback de eventos (inicio, pausa, etc.)
 * 
 * @param times Número de parpadeos
 * @param delayMs Tiempo en milisegundos entre encendido/apagado
 */
void blinkAllLEDs(int times, int delayMs) {
  for (int i = 0; i < times; i++) {
    digitalWrite(LED1, HIGH);
    digitalWrite(LED2, HIGH);
    digitalWrite(LED3, HIGH);
    digitalWrite(LED_STATUS, HIGH);
    delay(delayMs);
    digitalWrite(LED1, LOW);
    digitalWrite(LED2, LOW);
    digitalWrite(LED3, LOW);
    digitalWrite(LED_STATUS, LOW);
    delay(delayMs);
  }
}

// ========================================================================
// FUNCIONES AUXILIARES
// ========================================================================

/**
 * Calcula el tiempo transcurrido de tratamiento (excluyendo pausas)
 * 
 * @return Tiempo en milisegundos
 */
unsigned long getElapsedTreatmentTime() {
  if (currentState == IDLE || treatmentStartTime == 0) {
    return 0;
  }
  
  unsigned long totalElapsed = millis() - treatmentStartTime;
  
  // Restar el tiempo que estuvo en pausa
  unsigned long pauseTime = totalPausedTime;
  if (currentState == PAUSED) {
    pauseTime += (millis() - pauseStartTime);
  }
  
  return totalElapsed - pauseTime;
}

/**
 * MODO DE PRUEBA: Activa cada motor secuencialmente
 * Útil para verificar que todos los motores funcionan correctamente
 * Se activa manteniendo presionado el botón durante 5 segundos al inicio
 */
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

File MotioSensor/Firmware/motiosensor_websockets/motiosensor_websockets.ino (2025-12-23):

#include <Arduino.h>
#include <ESP8266WiFi.h>
#include <WebSocketsClient.h> 
#include <Wire.h>
#include "I2Cdev.h"
#include "MPU6050_6Axis_MotionApps20.h"
#include <SPI.h>
#include <SD.h>
#include <time.h> // Para la hora real

// --- DEFINICIONES ---
#define LED_CALIBRACION 2 // D4 (LED azul interno - active LOW)
#define LED_SD 0          // D3 (LED rojo externo - active HIGH)
#define INTERRUPT_PIN 15  // D8
#define CS_PIN 16         // D0
#define BLINK_INTERVAL 500 
#define RETRY_INTERVAL 5000 

// --- CREDENCIALES WIFI ---
const char* ssid = "iPhone de Jazmín";  // ⚠️ CAMBIAR: nombre de tu red WiFi
const char* password = "jazmin123";  

// --- RENDER (EIO=4) ---
const char* host = "motiometrics-backend.onrender.com";
const int port = 443; 
const uint8_t fingerprint[] = {
  0xA8, 0xEE, 0x46, 0x11, 0x10, 0x0C, 0x0E, 0x7D, 0x4E, 0x9D, 
  0x25, 0xEB, 0x63, 0x50, 0x68, 0x30, 0x45, 0x91, 0x6B, 0x28
}; // seguridad para conexiones HTTPS/SSL

// --- OBJETOS ---
WebSocketsClient webSocket;
MPU6050 mpu;
File dataFile;

// --- VARIABLES DE CONTROL ---
uint8_t FIFOBuffer[64];
Quaternion q; 
VectorFloat gravity;
float ypr[3];  // Yaw, Pitch, Roll - los ángulos de inclinación
VectorInt16 aa, aaReal; // aceleración lineal sin gravedad
uint16_t packetSize;
bool dmpOK = false;

// Variables de Tara
float initialYaw = 0; // La primera lectura válida se guarda como "punto cero" (initialYaw), así las mediciones empiezan desde 0.
bool initialYawSet = false;
int warmup_counter = 0;

// CONTROL DE FLUJO WIFI (DECIMACIÓN): Sirve para que el ESP8266 no intente enviar datos más rápido de lo que el WiFi o el servidor pueden procesar.
unsigned long lastWifiSend = 0;// Guarda el momento exacto (en milisegundos) en el que se envió el último paquete con éxito.
const int WIFI_INTERVAL = 40; // ~25fps Frecuencia de Transmisión: Si cambias 40 por 20, enviarás el doble de datos (50 veces por segundo).

// Variables SD y Estados
bool sd_presente = false;
bool wifi_habilitado = false;
bool isConnected = false; 
uint8_t fileNumber = 0;
unsigned long lastBlinkTime = 0;
unsigned long lastRetryTime = 0;
unsigned long lastFlush = 0;

// Enum
enum OperacionState {
  STATE_OK_SD,        
  STATE_FALLBACK_WIFI, 
  STATE_FAIL_TOTAL     
};
OperacionState estado_operacion = STATE_FAIL_TOTAL; // Valor por defecto seguro

// --- FUNCIONES AUXILIARES ---

String getNewFileName() {
    fileNumber++; 
    char filename[13]; 
    sprintf(filename, "mpu_data%02d.CSV", fileNumber);
    return String(filename);
}

bool iniciarArchivoSD() {
    String newFileName;
    int intentos = 0;
    do {
      newFileName = getNewFileName();
      intentos++;
    } while (SD.exists(newFileName) && fileNumber < 99 && intentos < 100);

    if (fileNumber >= 99 && SD.exists(newFileName)) {
       Serial.println("❌ Límite de archivos alcanzado.");
       return false;
    }

    dataFile = SD.open(newFileName.c_str(), FILE_WRITE);
    if (dataFile) {
      dataFile.println("Timestamp,Yaw,Pitch,Roll,Ax,Ay,Az");
      dataFile.flush(); 
      Serial.print("✅ Archivo creado: "); Serial.println(newFileName);
      return true;
    } else {
      Serial.print("❌ Error: No se pudo crear "); Serial.println(newFileName);
      return false;
    }
}

void handle_led_sd_blink() {
  if (estado_operacion == STATE_FAIL_TOTAL) {
    unsigned long currentMillis = millis();
    if (currentMillis - lastBlinkTime >= BLINK_INTERVAL) {
      lastBlinkTime = currentMillis;
      digitalWrite(LED_SD, !digitalRead(LED_SD)); // Toggle
    }
  }
  // En otros estados el LED se controla manualmente
}

String formatTime(unsigned long ms) {
  time_t now = time(nullptr);
  struct tm* timeinfo = localtime(&now);
  
  if (timeinfo->tm_year > 120) { // Hora de internet disponible
      char buffer[20];
      int msec = ms % 1000;
      sprintf(buffer, "%02d:%02d:%02d.%03d", timeinfo->tm_hour, timeinfo->tm_min, timeinfo->tm_sec, msec);
      return String(buffer);
  } 
  
  // Fallback tiempo relativo
  unsigned long totalSeconds = ms / 1000;
  int msec = ms % 1000;
  int seconds = totalSeconds % 60;
  int minutes = (totalSeconds / 60) % 60;
  int hours = (totalSeconds / 3600);
  char buffer[15];
  sprintf(buffer, "%02d:%02d:%02d.%03d", hours, minutes, seconds, msec);
  return String(buffer);
}

// --- EVENTOS WEBSOCKET ---
void webSocketEvent(WStype_t type, uint8_t * payload, size_t length) {
  switch(type) {
    case WStype_DISCONNECTED:
      Serial.println("[WS] Desconectado!");
      isConnected = false;
      break;
    case WStype_CONNECTED:
      Serial.println("[WS] Conectado! Esperando handshake...");
      break;
    case WStype_TEXT:
      char msgType = (char)payload[0];
      if(msgType == '0') {
        Serial.println("[EIO4] Sesión Abierta.");
        webSocket.sendTXT("40"); 
        isConnected = true;
      }
      else if(msgType == '4') {
        if((char)payload[1] == '0') Serial.println("[IO] ✅ CONEXIÓN OK");
      }
      else if(msgType == '2') {
        webSocket.sendTXT("3"); // PONG
      }
      break;
  }
}
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

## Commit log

2025-12-20 Reorganizacion de la estructura del repositorio
    [MotioSensor_KiCad.kicad_pcb, MotioSensor_KiCad.kicad_sch]
2025-12-20 Reorganizacion del repositorio
    [Plaqueta2.kicad_pcb, Plaqueta2.kicad_sch]
2025-12-21 Modificacion de analisis de datos
2025-12-23 Actualización MotioGlove y Websockets
    [MotioGlove.kicad_pcb, MotioGlove.kicad_sch, MotioGlove_ambaspartes.SLDPRT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]
2026-01-10 Organize desktop app files and track PyInstaller spec
